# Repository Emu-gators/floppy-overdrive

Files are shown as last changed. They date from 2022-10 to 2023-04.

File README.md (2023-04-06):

# `floppy-overdrive`

## Overview

A revival of the floppy disk drive and controller for modern computers. _Sending floppies into overdrive!_

## Organization

The project is laid out with the following directories:

- `docs`: relevant project documentation and research resources
- `hw`: HDL code and testbenches
- `pcb` : KiCad project for the control circuit PCB
- `pcb_tests` : Test code and procedures for the control circuit PCB
- `sw`: software code and scripts

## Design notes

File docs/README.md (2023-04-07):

## Documents

This folder contains information about the Floppy Overdrive project, including documentation, sources to information about floppy disks and drives, and a report an the current status of the project.

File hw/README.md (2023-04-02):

# Hardware

## Overview

This folder contains the files relevant to the hardware-based aspects of the Floppy Overdrive project, including HDL code and design schematics.

/ADC_Test contains the Verilog code for the partial ADC pulse generator circuit.
/control_board contains the Verilog code for the control circuit and the Makefiles for using it with the control board PCB.
/misc contains as-of-yet unused RTL files.

## FPGA Build Instructions

Build insturctions currently vary by circuit. Check the README file in the respective folders for further information on building each circuit for an FPGA device.

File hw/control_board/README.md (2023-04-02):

# Control Circuit

This folder contains the files needed for the control circuit portion of the Floppy Overdrive. This includes the Verilog code used to implement the control circuit (/rtl), a testbench used to verify this circuit (/tb), and the Make files needed to build the circuit for the control board PCB. 

## Build Instructions

To build the circuit for the PCB, the icestorm toolchain from http://www.clifford.at/icestorm/ and the iceFUN programmer from https://github.com/devantech/iceFUNprog are required.
These tools are currently only supported on Linux.

With a terminal open in this folder, enter the following commands to build the circuit and program it to the iceWerx FPGA:\
`make ctrl_board`\
`make burn`

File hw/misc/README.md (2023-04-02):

# Miscellaneous Files

This folder contains any leftover Verilog files that were created at the start of development, but have not yet been implemented into the project as a whole.

rw_circ.v contains the skeleton code for the read/write circuit, similar to ctrl_circ.v for the control circuit.\
overdrive_top.v contains the skeleton code for the top-level entity of the entire Floppy Overdrive, and is meant to instantiate both the control and read/write circuits and connect them to the necesarry sensors and buses.

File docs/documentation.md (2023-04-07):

# Floppy Overdrive - Documentation

## Introduction

The main task of the floppy drive is to provide and record data pulses onto a disk, using a specialized magnetic head that reacts to changes in magnetization on the disk. The motion of the drive (i.e. spinning the disk and moving the heads across the disk) is determined by an external floppy disk controller (FDC), which is generally installed inside of a PC. 

## Format

The 5.25-inch floppy disk stores data on a protected magnetic disk, using changes in magnetic flux to represent data. The disks is split up into several concentric rings, which are known as tracks. The first track is the outermost ring, with the track number increasing as they get closer to the center of the disk. These tracks are further subdivided into sectors, which has a specific number of bytes, depending on the logical format of the disk.

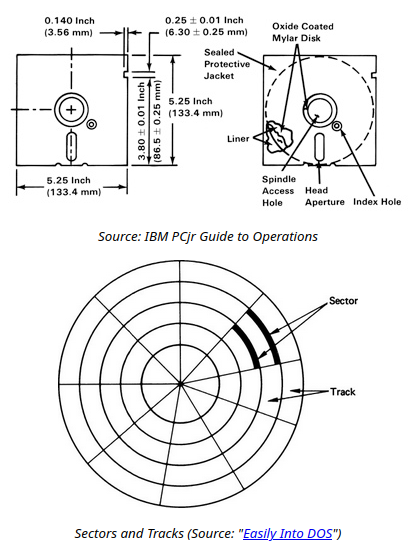
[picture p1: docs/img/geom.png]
\
Source: [21] in the research document.

There are two important physical features of the disk: the write-protect notch in the top-right corner, and the index hole just to the right of the center spindle. The drive uses a phototransistor and LED at the write-protect notch to notify the FDC if the disks is allowed to be written to. The disk is not write-protected when this notch is present, and it is write-protected when this notch is missing or covered up. The index hole corresponds to the start of sector 0 on the disk. When the hole spins around to match the hole in  the casing, a brief pulse is produced, which is sent to the FDC, and is one method of identifying the start of a track.

For the PC, there are two major types of 5.25-inch disks: 1.2MB high density (HD) disks and 320kB double density (DD or 2D) disks. Double density disks generally have 40 tracks, whereas high density disks have 80 tracks. The two types also are meant to be spun up at different speeds: 300 rpm for DD and 360 rpm for HD.

Since these two disks differ internally, it is important to consider whether a drive is able to read DD or HD disks. Generally, most high density 5.25 PC drives will use a density select signal, which changes the speed of the spindle motor to spin the disk at 300 or 360 rpm. DD disks can usually be read using a HD drive, but since HD drives have a much smaller read head, it is not recommended to write to a DD disk in an HD drive.

More information can be found in sources [6] and [21].

## Communication

The PC floppy drives connects directly to the FDC controller using a 34-pin bus. While this bus was never formally standardized and some pins will have different functions between drives and FDCs, there are a few standard signals needed to operate the drive:

- Index (Pin 8): The signal generated by the index sensor inside of the drive, where each pulse indicates that the start of the track is currently under the head.

- Drive select 1-4 (Pins 10, 12, 14, 6): Enable signals for up to 4 drives, where each drive is set to a specific number 1-4. In practice, only 2 drives could be connected to most FDCs, and each drive was set internally to drive 1, using a twist in the cable to swap one drive to drive 0. When a drive is not selected, it should not respond or send any signals on the bus.

- Motor on (Pin 16): The enable signal for the spindle motor, which can be activated independently of the drive select signal.

- Direction (Pin 18): Selects the direction of the magnetic head when a set pulse is sent. A low signal (ground) moves the head towards the center of the disk, while a high signal (+5V) moves it away from the center.

- Step (Pin 20): A low-level pulse on this line will cause the drive to step the head by one track on a rising edge.

- Track 0 (Pin 26): The signal created by the track 0 sensor of the drive, which indicates that the head is currently at track 0 of the disk.

- Write protect (Pin 28): The signal created by the write-protect sensor, where a low signal indicates that the current disk is write-protected.

- Read data (Pin 30): Used to send out the data pulses generated by the drive.

- Side select (Pin 32): Used by the FDC to tell the drive what side of the disk to read from. Side 0 (the upper head(?)) corresponds to a high signal, and side 1 corresponds to a low signal.

Only the even-numbered pins are used for communication, with all of the odd-numbered pins being connected to ground. Additionally, FDCs appear to mainly use +5V active-low logic, which should be accounted for when interfacing with the bus. When enabled, the drive should immediately react to any control signals and output the current state of the sensors.

More information about the floppy bus can be found in source [9].

## Control Circuit

The portion of the drive responsible for controlling the components and sensors of the drive is referred to as the control circuit. This is the more digital side of the drive, and for the most part consists of combinational logic. This section will specifically describe the behvaior of this circuit for the MF-504 drive, as is implemented on the control board.

Most of the sensors on the drive use phototransistors and LEDs to determine their states. All LEDs and transistors are able to be powered by +3.3V, with the exception of the index LED, which is on the spindle motor and is powered by its +12V supply. The write-protect and index signals are found on connector J4 of the PCB, while track 0 is on J6, the same header as the stepper motor. The disk sensor is a microswitch placed at the read of the drive, and is also connected at J4. All of the signals are active-high, expect for the index signal, which will be normally high but pulse low when the index hole is present.

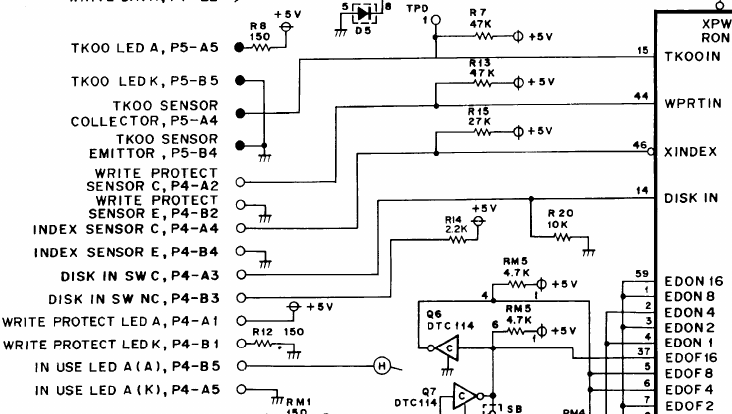
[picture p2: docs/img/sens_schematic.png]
\
The original schematics for wiring the drive sensors.

The logic for the sensors converts all inputs to be active-low, then ANDs them with the correct drive select line to determine whether to send their outputs. THe drive number is determined by a localparam in the control circuit module, which can be set manually before programming the FPGA.

The spindle motor is powered by +12V, but is able to use +3.3V logic. The motor has a speed and enable control on pins 1 and 3 of J2, respectively.
The motor will be disabled when pin 3 is low and begin spinning when high. When the speed control is low, the motor will spin at 300 rpm, and when it is high, the drive will spin at 360 rpm.

Since the control signal for the spindle motor is independent of the drive select, the motor signal from the bus is simply inverted to be active-high and sent directly to the motor. Similarly, the density signal is passed directly through the circuit to the speed control, as the levels for the signal on the bus match that of the motor itself.

The stepper motor of this drive is a four-wire unipolar stepper motor, also powered by +12V. A ULN2003 transistor array is used as the driver for this motor, which grounds a wire on the motor when the FPGA drives the corresponding input signal. In order to step the head forwards or backwards, one pin st a time must be grounded in sequence. For instance, grounding pin 1, then 2, then 3, then 4, then 1 again and so on would step the heads towards the center of the disk. Alternating the pins in the opposite order would result in the head moving away from the center of the disk. Each step should occur on the rising edge of a step pulse, and the direction of the step should be determined on this rising edge from the bus input.

More information on driving the stepper motor can be found in source [16].

A sub-circuit (step_driver_deb) has been created to drive the stepper motor. This circuit uses an FSM to detect the falling edge of a step pulse. It then waits for a certain number of cycles before checking if the pulse is still low to confirm that the step was valid and not just a result of bouncing. The FSM them waits for the step line to rise, and then changes the current coil according to the direction input. Due to potential issues with metastability on the step and direction inputs, a dual-flop synchronizer is used on both these inputs to ensure that there is a valid input to the FSM. THe pins ofn the FPGA corresponding to the four coils are wired directly to the ULN2003C, which in turn are connected to the stepper motor. 4 LEDs are also included on the control board to aid in identifying the currently grounded coil. These LEDs can be disabled by removing jumper JP1.

## Read Circuit

The read portion of the drive converts the waveform generated by the disks in the magnetic head to a series of encoded data pulses that the FDC can then decode into usable data.

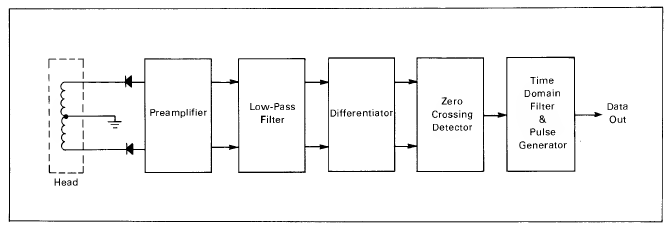
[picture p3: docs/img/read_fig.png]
\
Block diagram for a traditional read circuit [13].

The first portion of the read circuit is an amplifier that brings the voltage in the heads up from 1-2 mV to 100-200 mV. The signal produced will somewhat resemble a sine wave, where each of the peaks of the signal will correspond to a single data pulse. The signal from the magnetic heads will be a differential signal, centered at whatever the center voltage of the head is set to (Pin A2/B2, J5). For testing,  the center voltage was set to ground, and two THS4521 op-amps were used to produce a total of x100 gain on the signal, with a differential output.

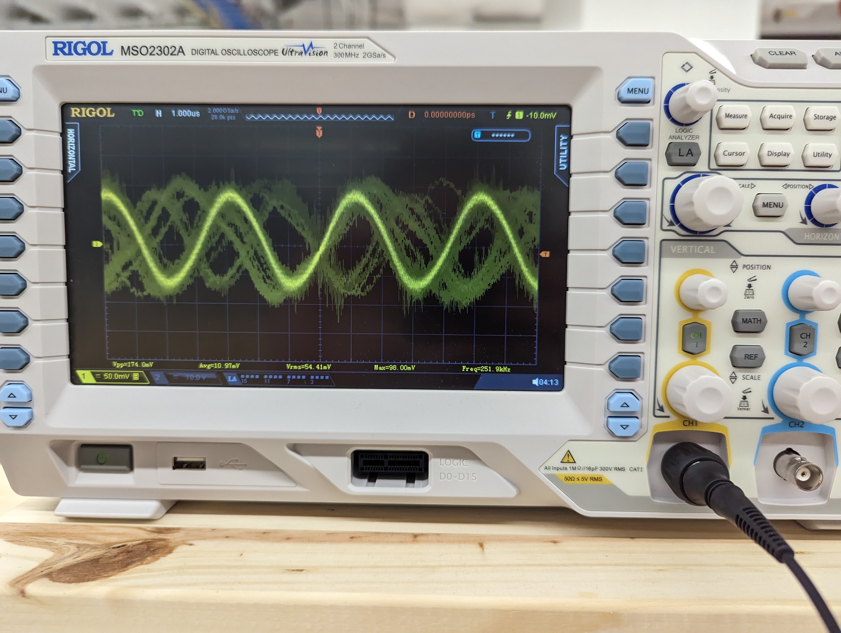
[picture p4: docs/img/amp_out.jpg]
\
The output of the preamplifier when connected to the magnetic heads. Only the positive end of the differential signal is connected here.

The data pulses correspond to each of the positive and negative peaks of this wave form. In the original analog circuitry, this signal would first be passed through a Pi filter, and then differentiated. This would convert the peak voltages into zero-crossings. A comparator would then be used to generate a square wave depending on whether the signal was above or below 0V. Each transition of the comparator would then trigger a pulse generator and a time-domain filter to generate the necessary pulses.

Source [13] goes much more in detail about how the data pulse recovery was performed in the original hardware.

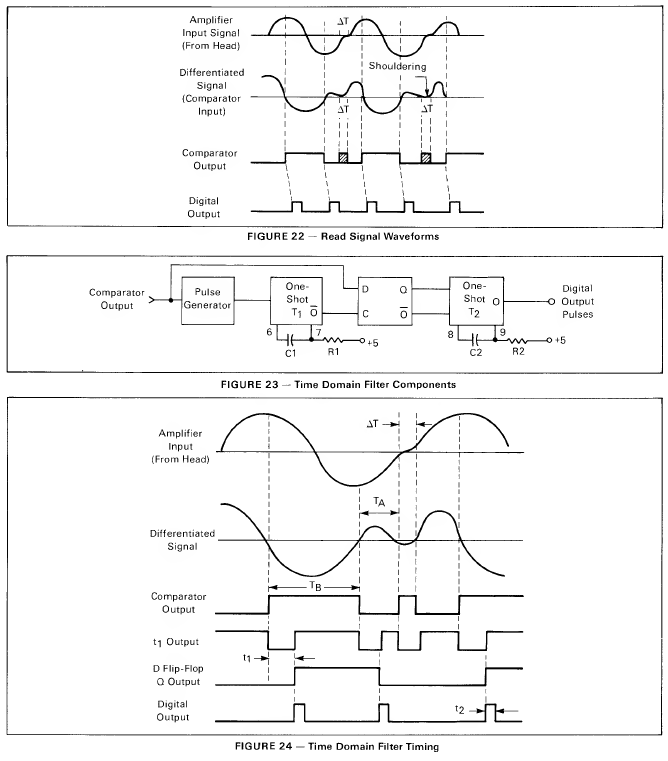
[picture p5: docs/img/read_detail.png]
\
A more descriptive set of diagrams for the read circuit [13].

Since an FPGA is being used for this project, a more digital approach to peak detection was tested, where the amplified signal would be read in using a high-speed ADC, and a data pulse would be generated when the ADC provided a value above or below a certain threshold.

To develop and test this circuit, the LTC1420, a 12-bit 10MSPS analog-to-digital converter, was chosen due to its parallel interface to the FPGA. This allowed for simpler communication logic than a serial ADC, and required a much lower clock speed for the FPGA while still sampling at a high frequency. The Verilog code written for the read circuit contained an FSM that would first read from the ADC, then pulse the data output and wait for a few microseconds when the ADC’s output passed the threshold before returning the the read state, where the FSM would remain until the output exceeded the threshold again.

During testing, it was found that the ADC would provide inconsistent maximum and minimum values, causing the pulses for the high and low peaks to be out of sync, producing a data pulse at inconsistent intervals. Additionally, the FPGA would occasionally produce a second pulse immediately after the first. This was reduced by increasing the threshold levels and adding a delay after ending the pulse, but the problem was not able to be solved fully. Possible sources of error include a lack of filtering on the input signal and improper wiring/ground decoupling of the ADC. All of the code used to test this circuit is provided in this repository under /hw/ADC_test.

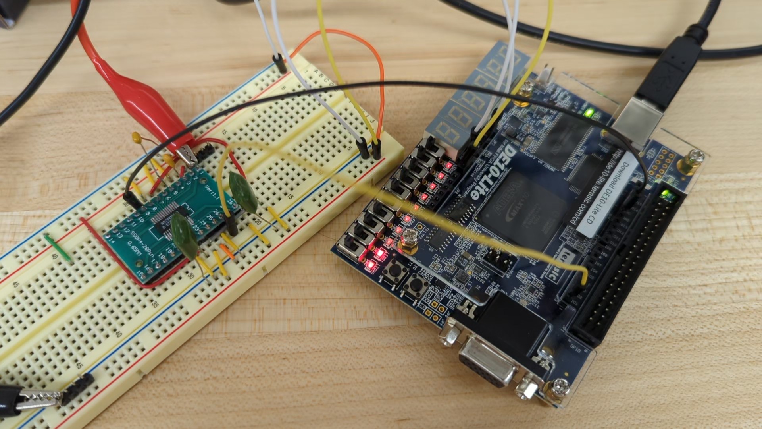
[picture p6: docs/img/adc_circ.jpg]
\
The ADC during testing, with only the MSB wired to the FPGA.

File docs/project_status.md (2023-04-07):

# Project Status (as of April 2023)

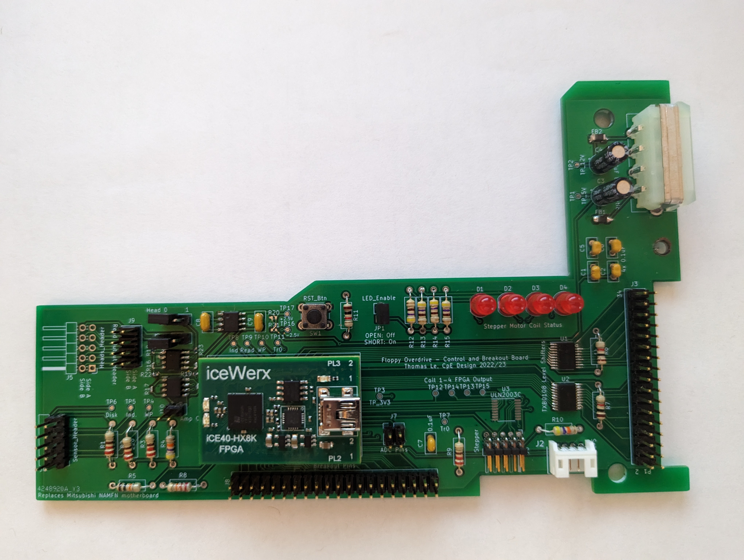
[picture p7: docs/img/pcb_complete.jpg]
\
The assembled PCB.

## PCB Issues

During testing, it was found that some aspects of the board do not function exactly as expected and will require later revisions to the design:

- The +/- 2.5V voltage generator (IC3, R20-21, C8-9) does not function and will not provide the correct voltages. When assembling the board, these components should be left unsoldered. The preamplifier circuit, however (IC1-2), does work as intended with the correct voltages, and can be powered directly from TP16-17 using an external power supply.

- When connecting the board to an ArduinoFDC, some pins will require extra pull-up resistors to +5V to prevent floating. This was noted in the motor enable signal, which would not return to +5V when the motor was disabled manually without this extra resistor. In testing, having all control lines appeared to provide good results, except for the Index signal, which would not provide a consistent waveform with this extra resistor. Further research into the traditional signal termination methods should be researched to resolve this issue.

- The new board will not lie flat in the drive without drilling an extra hole to fit the key pin at the read end of the drive. This has been corrected in the current KiCad project files, but should be noted when using the old revision of the board.

- Pin 39 on the breakout header is meant to be connected to +3.3V, but is not connected to any net. If desired, this can be solved by scratching off the silkscreen on the bottom layer to expose the +3.3V plane and soldering the pin directly. THis is also fixed in the current KiCad project files.

## Remaining Work

Most remaining work involves completing the read circuit. The preamplifier is done, but the peak detection still needs to be properly implemented. If the ADC can be properly interfaced with the FPGA, software peak detection in Verilog could still be an option for generating the read pulses. However, a better analog engineer might be able to more properly implement the filter, differentiator, and zero-crossing circuits used in the original hardware. The one-shots used for the time domain filter do not appear to be manufactured anymore, but they could probably be reimplemented in the FPGA, since at that point they are already just digital signals.

There also still needs to be a way to select between the different heads. One option would be to implement the entire circuit twice and mux the output in the FPGA, but obviously this is not a very elegant solution. The AN917 document discusses a few methods of disk selection, including using either diodes or FETs to enable one head or the other.

As was mentioned above, the input bus should be modified to match the specifications of the original drive and enure floating is not an issue. The standard specifications for the drive should provide some information on how to properly implement the input and output lines.

Once the read circuit is implemented, the entire design should be tested again using the ArduinoFDC to see if it is able to read any data, and then tested on real hardware to see if it is able to interface with an actual controller and computer.

Once the board functionality is completed, there is some room for expansion with the project. One idea might be to include a microcontroller on the board with the ArduinoFDC software installed, allowing the drive to function as a USB device so it can work without needing an external FDC. I also think there would be some merit to creating a method of recording the read waveforms of the heads as a different approach to archiving disks fully and in a way that might allow bad data to be better recovered.

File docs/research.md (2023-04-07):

# Research

## Overview

Various links to websites for learning about everything floppy: disks, drives, controllers, etc.

## Links

[1] https://extrapages.de/archives/20190102-Floppy-notes.html
- Overview of how data is encoded on floppy disks (FM, MFM).

[2] https://www.eit.lth.se/fileadmin/eit/courses/eitn50/Literature/fat12_description.pdf
- Information about the FAT12 filesystem used on some PC floppies.

[3] https://www.mouser.com/datasheet/2/268/37c78-468028.pdf
- Datasheet for a floppy disk controller.

[4] https://www.reddit.com/r/FPGA/comments/r9srq7/floppy_disk_controller_on_fpga/
- Reddit discussion about implementing an FDC on an FPGA.

[5] https://github.com/steve-chamberlin/fpga-disk-controller
- Apple II floppy implementation in Verilog and PCB files.

[6] https://www.hermannseib.com/documents/floppy.pdf
- 'The floppy user guide' - contains useful information about the types, layout, and formatting of disks.

[7] https://github.com/dhansel/ArduinoFDC
- Library for using an Arduino as a floppy disk controller.

[8] https://www.5volts.ch/posts/mfmreader/
- Overview of floppy disk data encoding and format.

[9] https://retrocmp.de/fdd/general/floppy-bus.htm
- Information about the 34-pin bus and the variations for each signal.

[10] https://archive.org/details/Teac_FD-55_Drive_Maintenance_Manual_1983_Teac_Corporation_of_America
- Service manual for the Teac FD-55 drive, a standard 5.25 inch drive.

[11] https://archive.org/details/bitsavers_shugartSA8oryofOperationsApr76_1380425
- Floppy drive theory of operation manual written by Shugart Associates, creators of the 5.25 inch drive.

[12] https://archive.org/details/bitsavers_mitsubishiMF504A347UAStandardSpecifications_1938078, https://archive.org/details/bitsavers_mitsubishiMF504A3TechnicalManual_883627, 
https://archive.org/details/bitsavers_mitsubishiMF504A347UASchematics_382555
- Specifications, service manuals, and schematics for the Mitsubishi MF504 used in this project. **Very useful** in identifying components and understanding the intended behavior of the drive.

[13] http://info-coach.fr/atari/hardware/_fd-hard/AN-917.pdf
- Application note AN917 on reading and writing data for a floppy disk. Essential document for understanding the theory of how data is recorded and read off of a disk.

[14] https://link.springer.com/content/pdf/10.1007/978-0-387-84927-0_3.pdf
- Publication on recovering data off of failing disks which also goes into some detail about the theory behind disk reading and writing.

[15] https://github.com/dhansel/ArduinoFDC
- A software FDC developed for Arduino-compatible boards. Currently the best method available for using the control board, due to its ability to manually control the spindle motor and step the head to an aribtrary track using the disk monitor feature.

[16] https://www.angelfire.com/journal2/paofiles/robotics/paoStepperMotors.htm
- Tutorial on testing and identifying the type of stepper motor used in a floppy drive.

[17] https://www.robot-electronics.co.uk/products/icewerx.html
- Product page for the Devantech iceWerx FPGA the PCB is designed around. Includes a pinout for the two headers.

[18] https://github.com/devantech/iceFUN
- Example projects for the iceWerx, which were adapted for the control circuit and pcb tests. Includes links to installing the icestorm toolchain and iceFun programmer.

[19] https://www.analog.com/media/en/technical-documentation/data-sheets/1420fa.pdf
- Datasheet for the LTC1420, the ADC that was tested for potential use in the read circuit.

[20] http://www.b-kainka.de/Daten/Analog/ne592.pdf
- Application note for the NE592, a much older amplifier, with an example circuit for a disk decoder circuit similar to those implemented on the original drives.

[21] http://brutmanlabs.org/Diskettes/Diskette_handling.html
- Another introduction to the basics and different types of floppy disks. Discusses DD vs HD disks and when to use one type in a certain drive.

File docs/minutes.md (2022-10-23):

# Meeting Minutes

A short log file for tracking meetings among the Emu-gators for the Floppy Overdrive project.

### 2022-10-23

Members:
- Thomas Le
- Chase Ruskin

Notes:
- create initial project
- collect research materials

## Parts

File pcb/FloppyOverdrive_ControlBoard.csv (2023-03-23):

Id | Designator | Package | Quantity | Designation | Supplier and ref
1 | C8,C9 | C_Disc_D5.0mm_W2.5mm_P2.50mm | 2 | 47u
2 | R22,R18,R23,R19 | R_0402_1005Metric | 4 | 1k
3 | JP1 | PinHeader_1x02_P2.54mm_Vertical | 1 | LED_Enable
4 | IC3 | SOIC127P600X175-8N | 1 | MAX660MX_NOPB
5 | D1 | LED_D5.0mm | 1 | LED1
6 | C7,C2,C1,C5,C6 | C_Disc_D5.0mm_W2.5mm_P2.50mm | 5 | 0.1u
7 | D4 | LED_D5.0mm | 1 | LED4
8 | TP3 | TestPoint_Pad_D1.0mm | 1 | TP_3V3
9 | R6,R7,R11 | R_Axial_DIN0207_L6.3mm_D2.5mm_P10.16mm_Horizontal | 3 | 1k
10 | J6 | PinHeader_2x05_P2.00mm_Horizontal | 1 | Step_Header
11 | J9 | PinHeader_2x04_P2.54mm_Vertical | 1 | HeadOut_Header
12 | R5 | R_Axial_DIN0207_L6.3mm_D2.5mm_P10.16mm_Horizontal | 1 | 10k
13 | TP2 | TestPoint_Pad_D1.0mm | 1 | TP_12V
14 | TP16 | TestPoint_Pad_D1.0mm | 1 | TP_-2V5
15 | TP1 | TestPoint_Pad_D1.0mm | 1 | TP_5V
16 | IC1,IC2 | SOIC127P600X175-8N | 2 | THS4521IDR
17 | J10 | PinHeader_1x02_P2.54mm_Vertical | 1 | Flop_ADC_Header
18 | R1,R3,R2,R9 | R_Axial_DIN0207_L6.3mm_D2.5mm_P10.16mm_Horizontal | 4 | 220
19 | R25,R17,R21,R20,R24,R16 | R_0402_1005Metric | 6 | 10k
20 | J5 | PinHeader_2x05_P2.54mm_Horizontal | 1 | Heads_Header
21 | TP14 | TestPoint_Pad_D1.0mm | 1 | TP_Coil2
22 | JP3 | PinHeader_1x03_P2.54mm_Vertical | 1 | HeadNeg_Sel
23 | TP5 | TestPoint_Pad_D1.0mm | 1 | TP_Index
24 | R10,R4 | R_Axial_DIN0207_L6.3mm_D2.5mm_P10.16mm_Horizontal | 2 | 47k
25 | C4,C3 | CP_Radial_D5.0mm_P2.00mm | 2 | 33u
26 | TP6 | TestPoint_Pad_D1.0mm | 1 | TP_Disk
27 | FB1,FB2 | R_1206_3216Metric | 2 | FerriteBead
28 | TP12 | TestPoint_Pad_D1.0mm | 1 | TP_Coil1
29 | U3 | TSSOP-16_4.4x5mm_P0.65mm | 1 | ULN2003
30 | J7 | PinHeader_2x02_P2.54mm_Vertical | 1 | PIC_ADC_Header
31 | TP7 | TestPoint_Pad_D1.0mm | 1 | TP_Track0
32 | TP15 | TestPoint_Pad_D1.0mm | 1 | TP_Coil4
33 | U4 | IceWerx FPGA | 1 | IceWerx FPGA
34 | TP4 | TestPoint_Pad_D1.0mm | 1 | TP_WP
35 | U1,U2 | TSSOP-20_4.4x6.5mm_P0.65mm | 2 | TXB0108-PW
36 | TP17 | TestPoint_Pad_D1.0mm | 1 | TP_2V5
37 | J2 | SHDRRA4W50P15X200_1X4_1000X770X525P | 1 | Motor_Header
38 | D3 | LED_D5.0mm | 1 | LED3
39 | J3 | PinHeader_2x17_P2.54mm_Vertical | 1 | Floppy_Bus
40 | J4 | PinHeader_2x05_P2.54mm_Horizontal | 1 | Sensor_Header
41 | TP13 | TestPoint_Pad_D1.0mm | 1 | TP_Coil3
42 | JP2 | PinHeader_1x03_P2.54mm_Vertical | 1 | HeadPos_Sel
43 | SW1 | SW_PUSH_6mm | 1 | RST_Btn
44 | TP10 | TestPoint_Pad_D1.0mm | 1 | TP_WP5V
45 | TP9 | TestPoint_Pad_D1.0mm | 1 | TP_Read5V
46 | R15,R12,R13,R14 | R_Axial_DIN0207_L6.3mm_D2.5mm_P10.16mm_Horizontal | 4 | 510
47 | J1 | 1748041 | 1 | 174804-1
48 | TP8 | TestPoint_Pad_D1.0mm | 1 | TP_Index5V
49 | R8 | R_Axial_DIN0207_L6.3mm_D2.5mm_P10.16mm_Horizontal | 1 | 22k
50 | J8 | PinHeader_2x20_P2.54mm_Vertical | 1 | FPGA_IO_Header
51 | D2 | LED_D5.0mm | 1 | LED2
52 | TP11 | TestPoint_Pad_D1.0mm | 1 | TP_Track05V

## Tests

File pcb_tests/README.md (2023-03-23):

# PCB Test Procedures and Code

## Test Procedures

A series of test procedures for the PCB are currently provided in the test_proc folder.
It is recommended that these procedures are followed once the PCB is assembed to ensure that the board is working correctly before it is used.
Some of these tests require loading test programs onto the FPGA device. These are provided in the additional folders here and can be programmed to the iceWerx FPGA.

## Code Build Instructions

To build the pcb test projects, the icestorm toolchain from http://www.clifford.at/icestorm/
and the iceFUN programmer from https://github.com/devantech/iceFUNprog are required.
These tools are currently only supported on Linux.

With a terminal open in the test's respective folder, enter the following commands:\
`make [TEST NAME]`\
`make burn`

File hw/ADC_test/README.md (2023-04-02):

# ADC Test Circuit

This folder contains the files created during the testing of the LTC1420 ADC circuit. Since these files are currently incomplete, they are provided without the files required to build them. These files were designed for the DE-10 Nano FPGA development board, but could be adapted to any FPGA device.

For reference, the schematic for the x100 gain preamplifier circuit is also provided here. This design is currently implemented on the control board and has been tested independedntly without any issues.

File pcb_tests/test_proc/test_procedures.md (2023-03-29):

# Floppy Overdrive - Control Board Test Procedures

## Section 1: Physical Inspection

### Visual Inspection
1. With the control board placed silkscreen side up, inspect the physical condition of the board. Compare the board against the provided schematic diagram to ensure that the shape matches and all silkscreen text is present.
2. Ensure that there are no visibly broken traces on the board. Attempt to follow each trace as closely as possible and repeat this process on both sides of the board.

### Board Fit Test
1. Remove the NAMFN control board from the Mitsubishi MF504A floppy drive. Retain the two screws from the connector side of the board.
2. Insert the control board into the drive, roughly aligning it with where the original board was placed.
3. Inspect the connector side screw holes from above. Ensure that the board’s screw holes align with those on the drive casing.
4. Using the original screws set aside, secure the control board in place and ensure that there is no interference between the screws and PCB while replacing them.

## Section 2: Power Testing

### Ground Continuity
1. Leave the board unplugged and the FPGA device removed.
2. Set a multimeter to continuity mode.
3. Keep one end of the multimeter on the ground strap on top of the power plug.
4. Run the other end of the multimeter along the odd-numbered pins of J3. All of these pins, as well as those in the following steps, should have continuity with ground.
5. Tap the other end of multimeter to pin 40 of J8 and confirm continuity.
6. Tap the multimeter to pin 32 of J2 and 36 of J3 and confirm continuity.
7. Tap the multimeter to pin 11 of U1 and 2 (bottom-right) and confirm continuity.
8. Tap the multimeter to pin 8 of U3 (bottom-left) and confirm continuity.
9. Tap the multimeter to pin 2 of IC1 and 2 (second down, left side) and confirm continuity.
10. Tap the multimeter to pins 3 and 6 of IC3 (third down, both sides) and confirm continuity.

### External Voltage Rails (+5V/+12V)
1. With the FPGA device removed, connect a 4-pin +5V/+12V power supply to the board at Header J1.
2. Connect the negative end of a multimeter to Pin 40 of Header J8 (GND).
3. Turn on the power supply.
4. Touch the positive end of the multimeter to test points TP1 (+5V) and TP2 (+12V). For each, ensure that the multimeter reads a proper voltage as expected on that line.
5. Touch the multimeter to pin 9 of U3 and ensure that the device is receiving 12 volts.
6. Touch the multimeter to pin 19 of U1 and U2 and ensure that each device is receiving 5 volts.
7. Touch the multimeter to pin 1 of J8 (the breakout pin header) and ensure that 5 volts is available on that pin.
8. Insert a wire into pin 35 of J3, device U4 and connect it to the multimeter. Ensure that 5 volts is present on that pin.
9. Disable the power supply.

### Amplifier Supply Voltage Rails (+/-2.5V)
1. With the FPGA device removed, connect a 4-pin +5V/+12V power supply to the board at Header J1.
2. Connect the negative end of a multimeter to Pin 40 of Header J8 (GND).
3. Turn on the power supply.
4. Touch the positive end of the multimeter to test point TP17 (+2.5V) and ensure that there is only POSITIVE 2.5 volts present.
5. Touch the positive end of the multimeter to test point TP16 (-2.5V) and ensure that there is only NEGATIVE 2.5 volts present.
6. When these voltages are confirmed, touch the positive end of the multimeter to pin 3 on IC1-2 to ensure those devices are receiving +2.5V.
7. Touch the positive end of the multimeter to pin 6 on IC1-2 to ensure those devices are also receiving -2.5V.

### FPGA Supply Voltage Rails (+3.3V)
1. With the FPGA device (U4) inserted in its socket, connect a 4-pin +5V/+12V power supply to the board at Header J1.
2. Connect the negative end of a multimeter to Pin 40 of Header J8 (GND) and the positive end to Pin 39 (+3.3V).
3. Turn on the power supply.
4. Ensure that the multimeter is reading +3.3V.
5. Touch the multimeter to pin 2 of U1 and U2 and ensure that each device is receiving +3.3V.
6. Touch the multimeter to pin 39 of J8 (the breakout pin header) and ensure that +3.3V is available on that pin.

## Section 3: Functionality Testing

## Floppy Bus Continuity
NOTE: When reprogramming the iceWerx FPGA, remove it from the control board to prevent any potential damage to the on-board components during the programming process.
1. Program the FPGA device with the code found in pcb_tests/floppy_bus.
2. Replace the FPGA in its socket on the control board.
3. Connect the negative end of an oscilloscope to Pin 1 of J3 (the 34-pin floppy bus).
4. Power on the control board.
5. For each even-numbered pin on J3 (excluding pin 4), connect the positive end of the oscilloscope. Verify that each pin is toggling at a frequency of about 500 Hz and only switches between +5V and 0V.

## External Header Continuity
1. Program the FPGA device with the code found in pcb_tests/external_header.
2. Replace the FPGA in its socket on the control board.
3. Connect the negative end of an oscilloscope to Pin 40 of J8 (ground on the breakout pins).
4. Power on the control board.
5. Starting at pin 2 and going up to pin 38, connect the positive end of the oscilloscope to each pin on the header. Verify that each pin is toggling at a frequency of about 500 Hz and only switches between +3.3V and 0V.

## Manual Disk Sensor Output
1. Prepare the MF504A drive and a floppy disk, ensuring that the index hole on the disk is not visible.
2. Connect headers J2, J4, and J6 to their respective connectors on the floppy drive.
3. Program the FPGA device with the code found in pcb_tests/sensors and replace it on the control board.
4. Connect the negative end of a multimeter to Pin 40 of J8 (ground on the breakout pins).
5. Power on the control board. 
6. With no disk inserted in the drive, touch the positive end of the multimeter to test points 4-6 by header J4. All three points should currently be at ground.
7. Touch the positive end of the multimeter to test points 8 and 10. 8 should be at ground while 10 should be at +3.3V.
8. Touch the positive end of the multimeter to pins 8 (Index) and 28 (Write Protect) on header J3. 8 should be at ground and 28 should be at +5V.
9. Insert a floppy disk in the drive just far enough to cover the write-protect sensor on the front-left side of the drive.
10. Repeat steps 7-9. The write protect signal should now be at +3.3V at TP4, and ground on TP10 and pin 28 at header J3.
11. Insert the disk far enough to cover the index sensor at the center of the drive, found near the spindle motor and connected by grey and purple wires.
12. Repeat steps 7-9. The index signal should now be at +3.3V at TP5 and 8, and at +5V at pin 8.
13. Insert the disk completely into the drive, triggering the disk latch.
14. Repeat steps 7-9. The index signal should match that seen in step 13 and TP6 should now be at +3.3V and the disk signal should be at +3.3V at TP6. If there is a write-protect notch present on the disk, the write-protect signal should now match match steps 7 and 8, otherwise it should match steps 11 and 13.

## Manual Track 0 Sensor Output
1. Prepare the MF504A drive and a floppy disk.
2. Connect headers J2, J4, and J6 to their respective connectors on the floppy drive.
3. Program the FPGA device with the code found in pcb_tests/sensors and replace it on the control board.
4. Before powering on the control board, gently push the magnetic heads towards the read end of the drive until it reached the end of the rails.
5. Connect the negative end of a multimeter to Pin 40 of J8 (ground on the breakout pins).
6. Power on the control board. 
7. Touch the positive end of the multimeter to test point 7. The test point should currently be at +3.3V.
8. Touch the positive end of the multimeter to test point 11. The test point should currently be at ground.
9. Touch the positive end of the multimeter to pin 26 on header J3. It should currently be at ground.
10. Power off the control board and gently push the head towards the front side of the drive until it moves about 1 cm.
11. Repeat steps 6-9. TP7 should be at ground, while TP11 and pin 26 should be at +3.3V and +5V, respectively.

## Manual Spindle Motor Input
1. Program the FPGA device with the code found in pcb_tests/spindle_manual and replace it on the control board.
2. Disconnect the spindle motor header (J2) from the control board.
3. Connect the negative end of the oscilloscope to pin 4 on that header (GND) and the positive end to pin 3 (motor control).
4. Connect a power supply to pin 16 (motor enable) of the input floppy bus (J3) and activate it at a level of +5V.
5. Power on the control board. With the power supply at +5V, the oscilloscope should show the motor control pin at ground.
6. Set the power supply to 0V. The oscilloscope should immediately show the pin at a value of +3.3V.
7. Power off the control board and power supply. Disconnect the oscilloscope and attach J6.
8. Repeat steps 5-6. When the power supply is at +5V, the spindle motor located in the center of the drive should not be spinning. At 0V, the spindle motor should be spinning.
9. With the board powered off, attach another power supply to pin 2 (density) on J3 and set it to +5V. Leave pin 16 at ground.
10. Power on the board. The drive should be spinning.
11. Set the power suply from +5V to ground. The spindle motor's speed should decrease in response.
12. Switch between ground and +5V several times, ensuring that the motor is able to switch between both speeds correctly.

## Automatic Stepper Motor Input
NOTE: Do not run this test while the stepper motor is connected (J3), otherwise the head may bang against the far edge of its range of motion, potentially damaging the stepper motor.
1. Program the FPGA device with the code found in pcb_tests/step_automatic and replace it on the control board.
2. Disconnect the stepper motor header from the control board and make sure jumper J1 is in place to activate the step LEDs.
3. Connect a power supply to pin 18 (step direction) of the floppy bus. Set it to +5V.
4. Power on the control board. Only one of the step LEDs should be enabled at a time, incrementing in regular intervals from D1 to D4, then repeating from D1.
5. Set the power supply to 0V. The LEDs should then blink in the opposite direction, counting down from D4 to D1.

## Manual Stepper Motor Input
1. Prepare a floppy disk to insert into the drive.
2. Program the FPGA device with the code found in pcb_tests/step_manual and replace it on the control board.
3. Disconnect the stepper motor header from the control board and make sure jumper J1 is in place to activate the step LEDs.
4. Connect a function generator to pin 20 (step) of the input floppy bus (J3). Set it to a square wave with a period of 11 ms and a 91% duty cycle, where the square wave is mostly at +5V and pulses to 0V.
5. Connect a power supply to pin 18 (step direction) of the floppy bus. Set it to +5V.
6. Power on the control board. Only one of the step LEDs should be enabled.
7. Trigger the function generator to send one pulse. The activated LED should shift in one direction.
8. Set the power supply to 0V and repeat the pulse. The original LED should be activated again.
9. Set the power supply back to +5V and send 5 pulses to the control board. The LEDs should be observed to increment from 1 to 4 and weap around to 1.
10. Set the power supply to 0V and send 5 pulses again. The same behavior should be observed in the opposite order as in step 8.
11. Set the power supply to +5V and send pulses continuously for 5 seconds. The LEDs should continue to increment in the same direction without stopping during this period.
12. Repeat step 10 with the power supply at 0V. The same behavior should be seen in the opposite direction.
13. Power off all devices, attach the stepper motor header to the board, and insert the disk into the drive.
14. Repeat steps 6-9, observing the motion of the drive’s magnetic head, where at +5V the head approaches the bus side of the drive, and at 0V it approaches the center of the disk.

## Controller Connection
1. Program the FPGA drive with the latest code release from /hw and replace it on the board.
2. Acquire an Arduino-compatible device and program it with the ArduinoFDC software controller from `https://github.com/dhansel/ArduinoFDC`.
3. Wire the Arduino to the control board, following the pinout provided for that device.
4. Connect all drive sensors and motors to the control board.
5. Power on the drive and the ArduinoFDC.
6. Using a serial monitor connected to the ArduinoFDC, set the drive mode to 5.25 High Density using the command `disktype 2`.
7. Insert a disk into the floppy drive.
8. Use the command `monitor` to enter monitor mode on the ArduinoFDC. The drive’s motor should be enabled immediately after sending this command.
9. Enter the command `m 0` to disable the spindle motor. The drive should react accordingly.
10. Step the drive to track 0 using  the command `r 0, 1`. The magnetic head should return to its home position, farthest away from the center of the drive, and the ArduinoFDC should specifically throw a low-level disk error. This indicates that no data is being read from the drive, which is expected as this functionality is not currently present.
11. Step the drive to an arbitrary track using the command `r [Track #], 1`. The drive should return to track 0 then step outwards to the requested track. The same low-level error should be seen.
12. Repeat step 11 with several different tracks up to the maximum of 79. On each command, the drive should be observed to step inwards, then outwards until it reached the requested track.

## Amplifier Output Testing
1. Program the FPGA device with the latest code release and replace it on the board.
2. Connect an oscilloscope to header J10.
3. Connect all drive sensors and motors to the control board.
4. Prepare a formatted blank high-density floppy disk.
5. Power on the control board.
6. Using the ArduinoFDC in monitor mode, step the drive to track 1, where no data should be present.
7. The oscilloscope should display a roughly sinusoidal signal of a frequency of ~250 kHz and an amplitude of 200 mV. The oscilloscope will likely not display a clean signal due to the nature of the formatting on the disk and the current lack of any filtering hardware.
This process also consists of the basic usage of the drive for any further development on the read circuit.

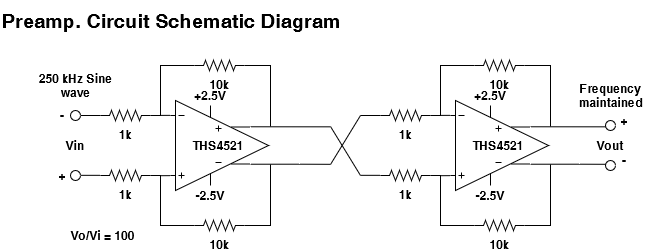
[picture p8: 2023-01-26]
hw/ADC_test/PreampTest.drawio.png

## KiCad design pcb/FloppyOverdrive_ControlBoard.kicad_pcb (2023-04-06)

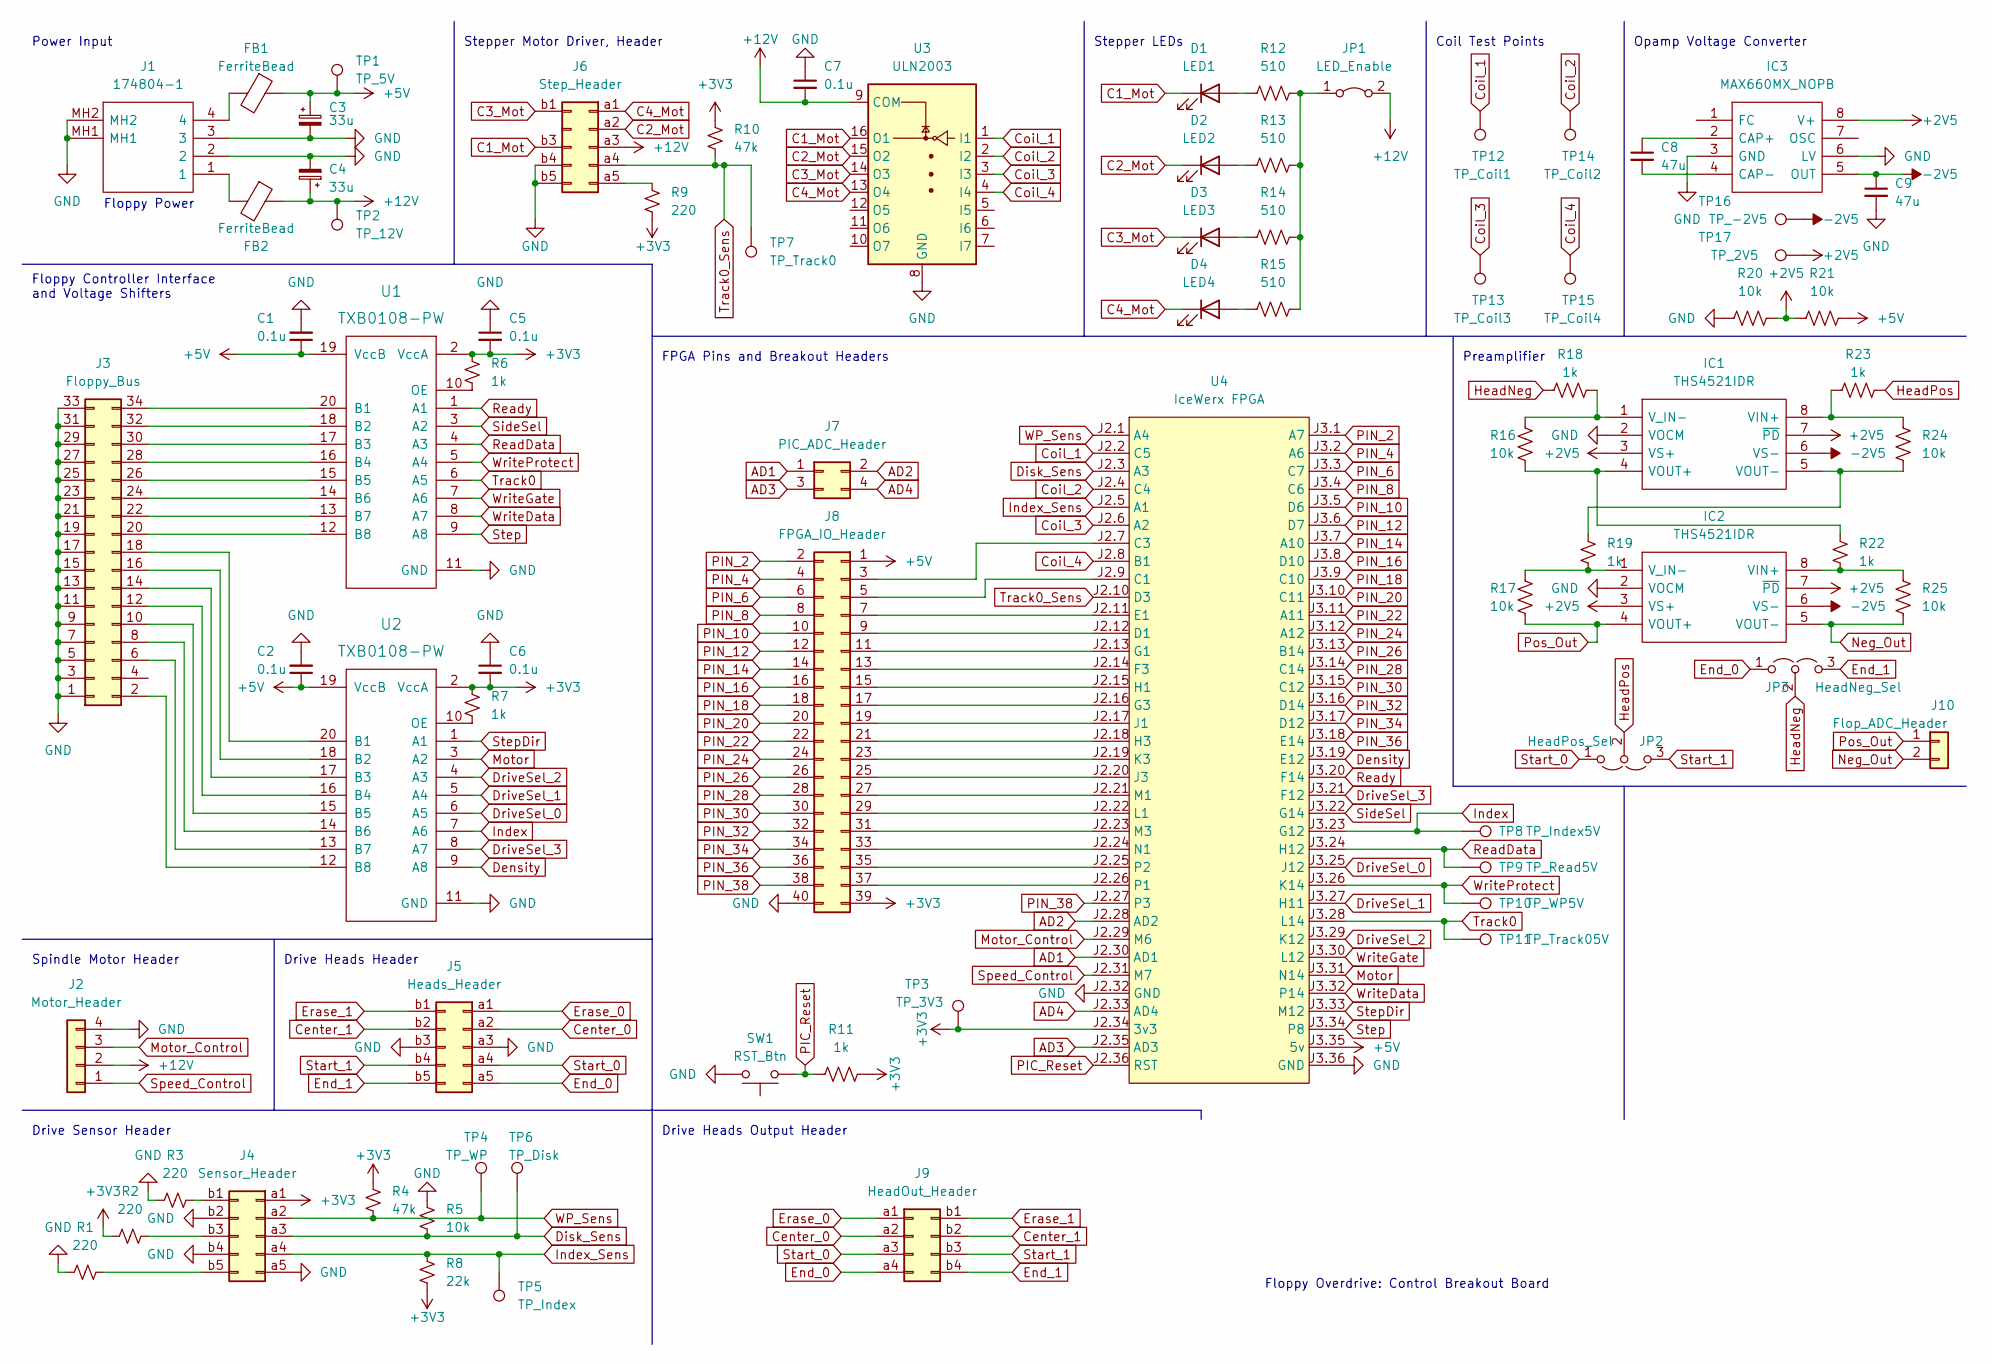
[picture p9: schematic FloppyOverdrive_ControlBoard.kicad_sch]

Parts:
C1, C2, C5, C6, C7: 0.1u; C_Disc_D5.0mm_W2.5mm_P2.50mm
C3, C4: 33u; CP_Radial_D5.0mm_P2.00mm
C8, C9: 47u; C_Disc_D5.0mm_W2.5mm_P2.50mm
D1: LED1; LED_D5.0mm
D2: LED2; LED_D5.0mm
D3: LED3; LED_D5.0mm
D4: LED4; LED_D5.0mm
FB1, FB2: FerriteBead; R_1206_3216Metric
IC1, IC2: THS4521IDR; SOIC127P600X175-8N; Mouser Part Number 595-THS4521IDR
IC3: MAX660MX_NOPB; SOIC127P600X175-8N; Mouser Part Number 926-MAX660MX/NOPB
J1: 174804-1; 1748041; Manufacturer_Part_Number 174804-1; Mouser Part Number 571-1748041
J2: Motor_Header; SHDRRA4W50P15X200_1X4_1000X770X525P
J3: Floppy_Bus; PinHeader_2x17_P2.54mm_Vertical
J4: Sensor_Header; PinHeader_2x05_P2.54mm_Horizontal
J5: Heads_Header; PinHeader_2x05_P2.54mm_Horizontal
J6: Step_Header; PinHeader_2x05_P2.00mm_Horizontal
J7: PIC_ADC_Header; PinHeader_2x02_P2.54mm_Vertical
J8: FPGA_IO_Header; PinHeader_2x20_P2.54mm_Vertical
J9: HeadOut_Header; PinHeader_2x04_P2.54mm_Vertical
J10: Flop_ADC_Header; PinHeader_1x02_P2.54mm_Vertical
JP1: LED_Enable; PinHeader_1x02_P2.54mm_Vertical
JP2: HeadPos_Sel; PinHeader_1x03_P2.54mm_Vertical
JP3: HeadNeg_Sel; PinHeader_1x03_P2.54mm_Vertical
R1, R2, R3, R9: 220; R_Axial_DIN0207_L6.3mm_D2.5mm_P10.16mm_Horizontal
R4, R10: 47k; R_Axial_DIN0207_L6.3mm_D2.5mm_P10.16mm_Horizontal
R5: 10k; R_Axial_DIN0207_L6.3mm_D2.5mm_P10.16mm_Horizontal
R6, R7, R11: 1k; R_Axial_DIN0207_L6.3mm_D2.5mm_P10.16mm_Horizontal
R8: 22k; R_Axial_DIN0207_L6.3mm_D2.5mm_P10.16mm_Horizontal
R12, R13, R14, R15: 510; R_Axial_DIN0207_L6.3mm_D2.5mm_P10.16mm_Horizontal
R16, R17, R20, R21, R24, R25: 10k; R_0402_1005Metric
R18, R19, R22, R23: 1k; R_0402_1005Metric
SW1: RST_Btn; SW_PUSH_6mm
TP1: TP_5V; TestPoint_Pad_D1.0mm
TP2: TP_12V; TestPoint_Pad_D1.0mm
TP3: TP_3V3; TestPoint_Pad_D1.0mm
TP4: TP_WP; TestPoint_Pad_D1.0mm
TP5: TP_Index; TestPoint_Pad_D1.0mm
TP6: TP_Disk; TestPoint_Pad_D1.0mm
TP7: TP_Track0; TestPoint_Pad_D1.0mm
TP8: TP_Index5V; TestPoint_Pad_D1.0mm
TP9: TP_Read5V; TestPoint_Pad_D1.0mm
TP10: TP_WP5V; TestPoint_Pad_D1.0mm
TP11: TP_Track05V; TestPoint_Pad_D1.0mm
TP12: TP_Coil1; TestPoint_Pad_D1.0mm
TP13: TP_Coil3; TestPoint_Pad_D1.0mm
TP14: TP_Coil2; TestPoint_Pad_D1.0mm
TP15: TP_Coil4; TestPoint_Pad_D1.0mm
TP16: TP_-2V5; TestPoint_Pad_D1.0mm
TP17: TP_2V5; TestPoint_Pad_D1.0mm
U1, U2: TXB0108-PW; TSSOP-20_4.4x6.5mm_P0.65mm
U3: ULN2003; TSSOP-16_4.4x5mm_P0.65mm
U4: IceWerx FPGA

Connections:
+2V5: IC1.3 (VS+), IC1.7 (~PD), IC2.3 (VS+), IC2.7 (~PD), IC3.8 (V+), R20.2, R21.1, TP17.1
+3V3: C5.2, C6.2, J4.a1, J8.39, R2.1, R4.1, R6.1, R7.1, R8.2, R9.2, R10.1, R11.2, TP3.1, U1.2 (VccA), U2.2 (VccA), U4.J2.34 (3v3)
+5V: C1.1, C2.1, C3.1, FB1.1, J8.1, R21.2, TP1.1, U1.19 (VccB), U2.19 (VccB), U4.J3.35 (5v)
+12V: C4.1, C7.2, FB2.1, J2.2, J6.a3, JP1.2 (B), TP2.1, U3.9 (COM)
-2V5: C9.1, IC1.6 (VS-), IC2.6 (VS-), IC3.5 (OUT), TP16.1
AD1: J7.1, U4.J2.30 (AD1)
AD2: J7.2, U4.J2.28 (AD2)
AD3: J7.3, U4.J2.35 (AD3)
AD4: J7.4, U4.J2.33 (AD4)
C1_Mot: D1.1 (K), J6.b3, U3.16 (O1)
C2_Mot: D2.1 (K), J6.a2, U3.15 (O2)
C3_Mot: D3.1 (K), J6.b1, U3.14 (O3)
C4_Mot: D4.1 (K), J6.a1, U3.13 (O4)
Center_0: J5.a2, J9.a2
Center_1: J5.b2, J9.b2
Coil_1: TP12.1, U3.1 (I1), U4.J2.2 (C5)
Coil_2: TP14.1, U3.2 (I2), U4.J2.4 (C4)
Coil_3: TP13.1, U3.3 (I3), U4.J2.6 (A2)
Coil_4: TP15.1, U3.4 (I4), U4.J2.8 (B1)
Density: U2.9 (A8), U4.J3.19 (E12)
Disk_Sens: J4.a3, R5.2, TP6.1, U4.J2.3 (A3)
DriveSel_0: U2.6 (A5), U4.J3.25 (J12)
DriveSel_1: U2.5 (A4), U4.J3.27 (H11)
DriveSel_2: U2.4 (A3), U4.J3.29 (K12)
DriveSel_3: U2.8 (A7), U4.J3.21 (F12)
End_0: J5.a5, J9.a4, JP3.1 (A)
End_1: J5.b5, J9.b4, JP3.3 (B)
Erase_0: J5.a1, J9.a1
Erase_1: J5.b1, J9.b1
GND: C1.2, C2.2, C3.2, C4.2, C5.1, C6.1, C7.1, C9.2, IC1.2 (VOCM), IC2.2 (VOCM), IC3.3 (GND), IC3.6 (LV), J1.2, J1.3, J1.MH1, J1.MH2, J2.4, J3.1, J3.3, J3.5, J3.7, J3.9, J3.11, J3.13, J3.15, J3.17, J3.19, J3.21, J3.23, J3.25, J3.27, J3.29, J3.31, J3.33, J4.a5, J4.b2, J4.b4, J5.a3, J5.b3, J6.b4, J6.b5, J8.40, R1.1, R3.1, R5.1, R20.1, SW1.2, U1.11 (GND), U2.11 (GND), U3.8 (GND), U4.J2.32 (GND), U4.J3.36 (GND)
HeadNeg: JP3.2 (C), R18.1
HeadPos: JP2.2 (C), R23.2
Index: TP8.1, U2.7 (A6), U4.J3.23 (G12)
Index_Sens: J4.a4, R8.1, TP5.1, U4.J2.5 (A1)
Motor: U2.3 (A2), U4.J3.31 (N14)
Motor_Control: J2.3, U4.J2.29 (M6)
Neg_Out: IC2.5 (VOUT-), J10.2, R25.2
unnamed: C8.1, IC3.2 (CAP+)
unnamed: C8.2, IC3.4 (CAP-)
unnamed: D1.2 (A), R12.1
unnamed: D2.2 (A), R13.1
unnamed: D3.2 (A), R14.1
unnamed: D4.2 (A), R15.1
unnamed: FB1.2, J1.4
unnamed: FB2.2, J1.1
unnamed: IC1.1 (V_IN-), R16.1, R18.2
unnamed: IC1.4 (VOUT+), R16.2, R22.1
unnamed: IC1.5 (VOUT-), R19.1, R24.2
unnamed: IC1.8 (VIN+), R23.1, R24.1
unnamed: IC2.1 (V_IN-), R17.1, R19.2
unnamed: IC2.8 (VIN+), R22.2, R25.1
unnamed: J3.2, U2.12 (B8)
unnamed: J3.6, U2.13 (B7)
unnamed: J3.8, U2.14 (B6)
unnamed: J3.10, U2.15 (B5)
unnamed: J3.12, U2.16 (B4)
unnamed: J3.14, U2.17 (B3)
unnamed: J3.16, U2.18 (B2)
unnamed: J3.18, U2.20 (B1)
unnamed: J3.20, U1.12 (B8)
unnamed: J3.22, U1.13 (B7)
unnamed: J3.24, U1.14 (B6)
unnamed: J3.26, U1.15 (B5)
unnamed: J3.28, U1.16 (B4)
unnamed: J3.30, U1.17 (B3)
unnamed: J3.32, U1.18 (B2)
unnamed: J3.34, U1.20 (B1)
unnamed: J4.b1, R3.2
unnamed: J4.b3, R2.2
unnamed: J4.b5, R1.2
unnamed: J6.a5, R9.1
unnamed: J8.3, U4.J2.7 (C3)
unnamed: J8.5, U4.J2.9 (C1)
unnamed: J8.7, U4.J2.11 (E1)
unnamed: J8.9, U4.J2.12 (D1)
unnamed: J8.11, U4.J2.13 (G1)
unnamed: J8.13, U4.J2.14 (F3)
unnamed: J8.15, U4.J2.15 (H1)
unnamed: J8.17, U4.J2.16 (G3)
unnamed: J8.19, U4.J2.17 (J1)
unnamed: J8.21, U4.J2.18 (H3)
unnamed: J8.23, U4.J2.19 (K3)
unnamed: J8.25, U4.J2.20 (J3)
unnamed: J8.27, U4.J2.21 (M1)
unnamed: J8.29, U4.J2.22 (L1)
unnamed: J8.31, U4.J2.23 (M3)
unnamed: J8.33, U4.J2.24 (N1)
unnamed: J8.35, U4.J2.25 (P2)
unnamed: J8.37, U4.J2.26 (P1)
unnamed: JP1.1 (A), R12.2, R13.2, R14.2, R15.2
unnamed: R6.2, U1.10 (OE)
unnamed: R7.2, U2.10 (OE)
PIC_Reset: R11.1, SW1.1, U4.J2.36 (RST)
PIN_2: J8.2, U4.J3.1 (A7)
PIN_4: J8.4, U4.J3.2 (A6)
PIN_6: J8.6, U4.J3.3 (C7)
PIN_8: J8.8, U4.J3.4 (C6)
PIN_10: J8.10, U4.J3.5 (D6)
PIN_12: J8.12, U4.J3.6 (D7)
PIN_14: J8.14, U4.J3.7 (A10)
PIN_16: J8.16, U4.J3.8 (D10)
PIN_18: J8.18, U4.J3.9 (C10)
PIN_20: J8.20, U4.J3.10 (C11)
PIN_22: J8.22, U4.J3.11 (A11)
PIN_24: J8.24, U4.J3.12 (A12)
PIN_26: J8.26, U4.J3.13 (B14)
PIN_28: J8.28, U4.J3.14 (C14)
PIN_30: J8.30, U4.J3.15 (C12)
PIN_32: J8.32, U4.J3.16 (D14)
PIN_34: J8.34, U4.J3.17 (D12)
PIN_36: J8.36, U4.J3.18 (E14)
PIN_38: J8.38, U4.J2.27 (P3)
Pos_Out: IC2.4 (VOUT+), J10.1, R17.2
ReadData: TP9.1, U1.4 (A3), U4.J3.24 (H12)
Ready: U1.1 (A1), U4.J3.20 (F14)
SideSel: U1.3 (A2), U4.J3.22 (G14)
Speed_Control: J2.1, U4.J2.31 (M7)
Start_0: J5.a4, J9.a3, JP2.1 (A)
Start_1: J5.b4, J9.b3, JP2.3 (B)
Step: U1.9 (A8), U4.J3.34 (P8)
StepDir: U2.1 (A1), U4.J3.33 (M12)
Track0: TP11.1, U1.6 (A5), U4.J3.28 (L14)
Track0_Sens: J6.a4, R10.2, TP7.1, U4.J2.10 (D3)
WP_Sens: J4.a2, R4.2, TP4.1, U4.J2.1 (A4)
WriteData: U1.8 (A7), U4.J3.32 (P14)
WriteGate: U1.7 (A6), U4.J3.30 (L12)
WriteProtect: TP10.1, U1.5 (A4), U4.J3.26 (K14)

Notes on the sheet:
FPGA Pins and Breakout Headers
Drive Sensor Header
Spindle Motor Header
Floppy Controller Interface and Voltage Shifters
Stepper Motor Driver, Header
Preamplifier
Drive Heads Header
Stepper LEDs
Floppy Overdrive: Control Breakout Board
Floppy Power
Coil Test Points
Opamp Voltage Converter
Drive Heads Output Header
Power Input

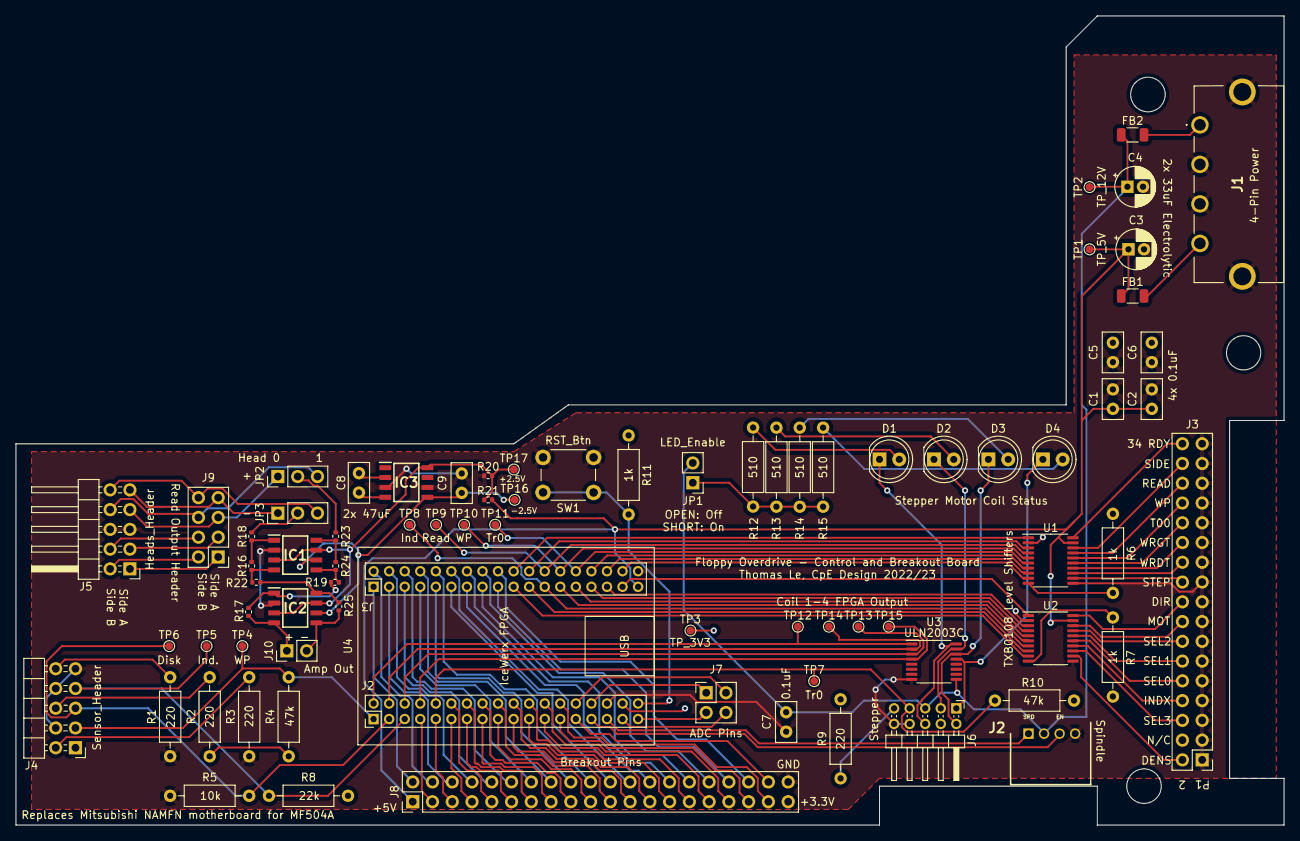
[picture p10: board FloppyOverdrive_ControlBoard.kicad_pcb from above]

Board: 2 copper layers, 163.0 x 104.0 mm, 78 parts (0 on the bottom side), 127 nets.

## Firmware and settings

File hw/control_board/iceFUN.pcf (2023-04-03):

# For iceWERX board

set_io --warn-no-port clk  	   P7
set_io --warn-no-port motor_in N14
set_io --warn-no-port dens_in  E12
set_io --warn-no-port step_in  P8
set_io --warn-no-port dir_in   M12
set_io --warn-no-port tr0_sens D3
set_io --warn-no-port dsk_sens A3
set_io --warn-no-port wpr_sens A4
set_io --warn-no-port ind_sens A1
set_io --warn-no-port spin_en  M6
set_io --warn-no-port spin_ss  M7
set_io --warn-no-port step_0   C5
set_io --warn-no-port step_1   C4
set_io --warn-no-port step_2   A2
set_io --warn-no-port step_3   B1
set_io --warn-no-port tr0_out  L14
set_io --warn-no-port ind_out  G12
set_io --warn-no-port wpr_out  K14
set_io --warn-no-port dsk_LED  M4
set_io --warn-no-port clk_out  A5

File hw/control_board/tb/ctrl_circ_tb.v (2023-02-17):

/* Floppy Overdrive - Sub-Level Entity Testbench
 *
 * File: ctrl_circ_tb.v
 * Author: Thomas Le <thomas.le@ufl.edu>
 * Created: Feb. 5, 2023
 *
 * Simulation testbench for the controller circuit entity.
 */

 `timescale 1ns/10ps

 module ctrl_circ_tb;
    reg clk, rst;

    // External interface
    reg dens_sel;        // Pin 2 - Density select
    wire index;           // Pin 8 - Index
    reg [3:0] drive_sel; // Pins 6, 10-14 - Drive Select 0-3
    reg motor_on;        // Pin 16 - Motor on
    reg dir_sel;         // Pin 18 - Direction select
    reg step;            // Pin 20 - Step head
    wire track_0;         // Pin 26 - Track 00 sensor
    wire wr_protect;      // Pin 28 - Write protect sensor

    // Motors 
    wire spin_en;    // Spindle motor enable
    wire spin_ss;    // Spindle speed select (1 = 360rpm, 0 = 300 rpm)
    wire [3:0] step_drv; // To 4-coil stepper motor driver (ULN2003C)

    // Sensors
    reg ind_sens;
    reg t00_sens;
    reg wpr_sens;
    reg dsk_sens;

    // Define the module for the controller interface
    ctrl_circ U_CTRL(.clk, .rst, .dens_sel(dens_sel), .index(index), .drive_sel(drive_sel), .motor_on(motor_on),
                     .dir_sel(dir_sel), .step(step), .track_0(track_0), .wr_protect(wr_protect),
                     .spin_en(spin_en), .spin_ss(spin_ss), .step_drv(step_drv), .ind_sens(ind_sens),
                     .t00_sens(t00_sens), .wpr_sens(wpr_sens), .dsk_sens(dsk_sens));

    localparam half_clock = 50;
    localparam full_clock = 100; // 10 MHz
    localparam step_time = 500000; // 0.55 ms;
    localparam drive_num = 1;

    // Clock pulse generator - the clock will rise and fall every 50ns to give a total period of 100 ns (10 MHz)
    always
    begin
        clk = 1'b1;
        #half_clock;
        clk = 1'b0;
        #half_clock;
    end

    // Tests - Various inputs to the controller circuit will be tested in this block sequentially,
    // and each output will be asserted against the expected output
    always @(posedge clk)
    begin
        // Reset inputs to their default states
        rst = 1'b1;
        drive_sel = 4'b1111; // Drive disabled
        dens_sel = 1'b1;
        motor_on = 1'b1;
        dir_sel = 1'b1;
        step = 1'b1;
        ind_sens = 1'b1; // This sensor is HIGH on FALSE
        t00_sens = 1'b0; // This sensor is LOW on FALSE
        wpr_sens = 1'b0; // This sensor is LOW on FALSE
        dsk_sens = 1'b0; // This sensor is LOW on FALSE
        #full_clock
        #full_clock

        // TEST BLOCK
        // The currently selected drive is not the controller - no inputs or outputs should be read
        rst = 1'b0;

        // Motor test - independent of drive select, the motor should be able to be enabled or disabled
        motor_on = 1'b0; // Enable signal (active-low)
        #full_clock; // Wait for a full clock cycle
        if(spin_en != 1'b1) // Incorrect: Motor is currently off
            $display("No select: Motor not turned on at high speed");
        else if(spin_ss != 1'b1) // Incorrect: Motor is currently at a low speed
            $display("No select: Motor on, not set to high speed");
        
        // Density select - Motor should spin at the slower speed (speed select is low)
        dens_sel = 1'b0;
        #full_clock;
        if(spin_en != 1'b1)
            $display("No select: Motor not turned on at low speed");
        else if(spin_ss != 1'b0)
            $display("No select: Motor on, not set to low speed");
        
        // Disable motor
        motor_on = 1'b1;
        dens_sel = 1'b1;

        // Sensor tests - Each test first enables their corresponding sensors and then asserts against the outputs to make sure that they are on (or off) as expected
        // No outputs should be seen since the drive is not selected
        if(index != 1'b1)
            $display("No select: Index output when no input present");

        if(track_0 != 1'b1)
            $display("No select: Track 0 output when no input present");

        if(wr_protect != 1'b1)
            $display("No select: Write protect output when no input present");

        // Asserting the index signal alone
        ind_sens = 1'b0; // On
        #full_clock;
        if(index != 1'b1)
            $display("No select: Index output when drive is not selected");

        if(track_0 != 1'b1)
            $display("No select: Track 0 output when input present on index");

        if(wr_protect != 1'b1)
            $display("No select: Write protect output when input present on index");

        // Asserting the track 0 signal alone
        ind_sens = 1'b1; // Off
        t00_sens = 1'b1; // On
        #full_clock;
        // Checking the outputs - display an error when does not match expected
        if(index != 1'b1)
            $display("No select: Index output when input present on t00");

        if(track_0 != 1'b1)
            $display("No select: Track 0 output when drive is not selected");

        if(wr_protect != 1'b1)
            $display("No select: Write protect output when input present on t00");

        // Write protect alone
        t00_sens = 1'b0; // Off
        wpr_sens = 1'b1; // On
        #full_clock;
        if(index != 1'b1)
            $display("No select: Index output when input present on write protect");

        if(track_0 != 1'b1)
            $display("No select: Track 0 output when input present on write protect");

        if(wr_protect != 1'b1)
            $display("No select: Write protect output when drive is not selected");

        // Index and track 0
        ind_sens = 1'b0; // On
        t00_sens = 1'b1; // On
        wpr_sens = 1'b0; // Off
        #full_clock;
        if(index != 1'b1)
            $display("No select: Index output when drive is not selected");

        if(track_0 != 1'b1)
            $display("No select: Track 0 output when drive is not selected");

        if(wr_protect != 1'b1)
            $display("No select: Write protect output when input present on index and t00");

        // Index and write protect
        ind_sens = 1'b0; // On
        t00_sens = 1'b0; // Off
        wpr_sens = 1'b1; // On
        #full_clock;
        if(index != 1'b1)
            $display("No select: Index output when drive is not selected");

        if(track_0 != 1'b1)
            $display("No select: Track 0 output when input present on index and write protect");

        if(wr_protect != 1'b1)
            $display("No select: Write protect output when drive is not selected");

        // Track 0 and write protect
        ind_sens = 1'b1; // Off
        t00_sens = 1'b1; // On
        wpr_sens = 1'b1; // On
        #full_clock;
        if(index != 1'b1)
            $display("No select: Index output when input present on t00 and write protect");

        if(track_0 != 1'b1)
            $display("No select: Track 0 output when drive is not selected");
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

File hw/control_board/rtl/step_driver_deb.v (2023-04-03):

/* Floppy Overdrive - Sub-Level Entity
 *
 * File: step_driver_deb.v
 * Author: Thomas Le <thomas.le@ufl.edu>
 * Created: Jan. 20, 2023
 *
 * This module handles the control logic for the 4 stepper motor coils.
 * When a valid step signal is recieved, the current coil is shifted
 * left or right, moving the stepper motor one 'step' in a particular direction.
 *
 * Unlike step_driver.v, this module adds a CHECK and COUNT state to ensure that
 * the step pulse is of a minimum length. This prevents the motor from stepping
 * when bounces occur on the step input.
 */

module step_driver_deb(
	input wire clk,
	input wire rst,

	input wire step,
	input wire dir,
	
	input wire tr0,
	input wire en,
	
	output wire [3:0] coils
	);
	
	localparam DELAY_COUNT = 8'd500; // Defines length of delay before checking for bounce

	// Stepper motor coils
	reg [3:0] coil_state_r, next_coil; 
	assign coils = coil_state_r;

	// Counter for bounce delay
	reg [7:0] count_r, next_count;

	// FSM states and state register
	localparam LOAD  = 3'b000;
	localparam START = 3'b001;
	localparam COUNT = 3'b010;
	localparam CHECK = 3'b011;
	localparam WAIT  = 3'b100;
	localparam STEP  = 3'b101;
	reg [2:0] state_r, next_state;

	// Step and direction inputs for dual-flop synchronizers
	reg step_del_r, step_r;
	reg dir_del_r, dir_r;

	always @(posedge clk, posedge rst) begin
		if(rst == 1'b1) begin
			coil_state_r <= 4'b0001;
			state_r <= 3'b000;
			count_r <= 8'b00000000;
			step_del_r <= 1'b1;
			step_r <= 1'b1;
			dir_del_r <= 1'b1;
			dir_r <= 1'b1;
		end else begin
			state_r <= next_state;
			coil_state_r <= next_coil;
			count_r <= next_count;
			
			// Dual-flop synchronizer, prevents possible metastability on step signal
			step_del_r <= step;
			step_r <= step_del_r;
			
			// Dual-flop for direction signal
			dir_del_r <= dir;
			dir_r <= dir_del_r;
		end
	end

	always @* begin
		next_state = state_r;
		next_coil = coil_state_r;
		next_count = count_r;
		
		case(state_r)
			LOAD: begin // Makes sure first coil is energized at start of execution
				next_coil = 4'b0001;
				next_state = START;
			end

			START: begin
				if((en == 1'b1) && (step_r == 1'b0)) begin // If the step line goes low and the drive is enabled
					next_state = COUNT; // Go to COUNT
					next_count = DELAY_COUNT; // Start counter from max. value
					//next_coil  = 4'b1010;
				end
			end
			
			COUNT: begin
				if(count_r == 8'd0) begin // If end of timer is reached
					next_state = CHECK; // Go to CHECK
				end else begin
					next_count = count_r - 8'b00000001; // Count down from 0
				end
			end
			
			CHECK: begin
				if(step_r == 1'b1) begin // Step line is no longer low, implies bounce
					next_state = START; // Go to START
				end else begin
					next_state = WAIT; // Go to WAIT
				end
			end
			
			WAIT: begin
				if(step_r == 1'b1) begin // Wat to step until the rising edge of the step signal
					next_state = STEP; // Go to STEP
				end
			end
			
			STEP: begin
				if(dir_r == 1'b0) begin // dir = low: step towards center of disk, coils 1>2>3>4>1...
					case(coil_state_r)
						4'b0001: next_coil = 4'b0010;
						4'b0010: next_coil = 4'b0100;
						4'b0100: next_coil = 4'b1000;
						4'b1000: next_coil = 4'b0001;
						default: next_coil = 4'b0001;
					endcase
				end else if(dir_r == 1'b1) begin // dir - high: step towards edge of disk, coils 4>3>2>1>4...
					case(coil_state_r)
						4'b0001: next_coil = 4'b1000;
						4'b0010: next_coil = 4'b0001;
						4'b0100: next_coil = 4'b0010;
						4'b1000: next_coil = 4'b0100;
						default: next_coil = 4'b0001;
					endcase
				end
			
				next_state = START; // Go to START
			end
			
			default: begin // Undefined state
				next_state = START; // Go to START
				next_count = 8'b0; // Clear counter
			end
		endcase
	end
endmodule // step_driver_deb

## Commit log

2022-11-01 adds controller circuit interface
2022-11-01 adds read/write circuit interface
2022-11-01 fixes commented-out misspelled wire name
2023-01-20 Rewrote step driver to add debounce
2023-01-26 Added schematics for test circuits
2023-02-14 Added pcb files
    [FloppyOverdrive_ControlBoard.kicad_pcb, FloppyOverdrive_ControlBoard.kicad_sch]
2023-02-14 Add motor header files, outline for PCB
    [FloppyOverdrive_ControlBoard.kicad_pcb, FloppyOverdrive_ControlBoard.kicad_sch]
2023-02-16 Added LEDs, footprints to PCB schematic
    [FloppyOverdrive_ControlBoard.kicad_sch]
2023-02-17 PCB Update
    [FloppyOverdrive_ControlBoard.kicad_pcb, FloppyOverdrive_ControlBoard.kicad_sch]
2023-02-18 Added ADC files
2023-02-18 Worked on PCB layout, began adding test points
    [FloppyOverdrive_ControlBoard.kicad_pcb, FloppyOverdrive_ControlBoard.kicad_sch]
2023-02-20 Routing first draft
    [FloppyOverdrive_ControlBoard.kicad_pcb, FloppyOverdrive_ControlBoard.kicad_sch]
2023-02-21 Fixed incorrect routing, added silkscreen info
    [FloppyOverdrive_ControlBoard.kicad_pcb]
2023-02-21 Fixed floppy bus orientation
    [FloppyOverdrive_ControlBoard.kicad_pcb, FloppyOverdrive_ControlBoard.kicad_sch]
2023-02-22 Added PCB test points, fixed schematic
    [FloppyOverdrive_ControlBoard.kicad_pcb, FloppyOverdrive_ControlBoard.kicad_sch]
2023-02-22 Sync backups
    [FloppyOverdrive_ControlBoard.kicad_pcb]
2023-02-23 Backup sync
    [FloppyOverdrive_ControlBoard.kicad_pcb]
2023-02-27 Adjusted screw holes
    [FloppyOverdrive_ControlBoard.kicad_pcb]
2023-02-27 Generated BOM
    [FloppyOverdrive_ControlBoard.csv]
2023-03-02 Added neg voltage and amps
    [FloppyOverdrive_ControlBoard.kicad_pcb, FloppyOverdrive_ControlBoard.kicad_sch]
2023-03-03 Generated gerbers
    [FloppyOverdrive_ControlBoard-B_Cu.gbr, FloppyOverdrive_ControlBoard-B_Mask.gbr, FloppyOverdrive_ControlBoard-B_Paste.gbr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]
2023-03-06 Updated BOM
    [FloppyOverdrive_ControlBoard.csv]
2023-03-23 Added sensor tests
2023-03-23 Added motor tests
2023-03-23 Modified pcb_tests README
2023-03-23 Fixed pin 39, added missing hole to PCB
    [FloppyOverdrive_ControlBoard.kicad_pcb, FloppyOverdrive_ControlBoard.kicad_sch]
2023-03-23 Bugfixes for pcb tests
    [iceFUN.pcf]
2023-03-29 Added bus pinout to silkscreen
    [FloppyOverdrive_ControlBoard.kicad_pcb]
2023-04-03 Control circuit bugfixes
2023-04-06 Added spin info to silkscreen
    [FloppyOverdrive_ControlBoard.kicad_pcb]
